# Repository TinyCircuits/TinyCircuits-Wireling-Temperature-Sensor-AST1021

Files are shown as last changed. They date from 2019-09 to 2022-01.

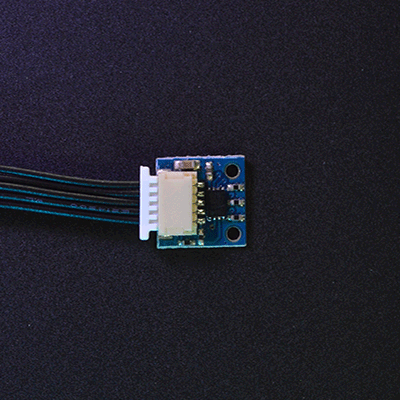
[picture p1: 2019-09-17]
images/AST1021-Tutorial-Animation-01.gif

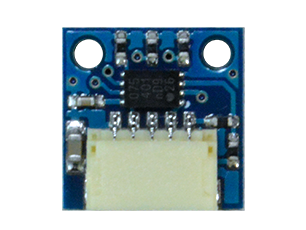
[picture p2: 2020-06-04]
images/AST1021-Learn-Photo-01.png

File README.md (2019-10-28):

# TinyCircuits Wireling Temperature Sensor
# AST1021 Rev2

The design files are located under design_files/ for the TinyCircuits AST1021 Rev 2 PCB. This is a Wireling board which features the PCT2075 Temperature Senor with 11-bit output. You've probably already guessed correctly that this sensor helps you measure the temperature in a given environment.

Format is in Cadsoft Eagle format - Eagle version 6.2 was used for the original design.

For more infomation on this, check out the product page at TinyCircuits.com

# License:

Design by TinyCircuits.
All design files are released under the Creative Commons Attribution Share-Alike 3.0 License, see the following link for details: http://creativecommons.org/licenses/by-sa/3.0

All text above must be included in any redistribution or derived design

This project uses designs and concepts developed as part of the Arduino project and the LilyPad project.  The TinyCircuits design files themselves (schematics, PCB and libraries) are not directly derived from these works' design files and have been created new, however the concepts and basic architecture behind the TinyDuino and TinyLily products are derived and we thank the hard work of the organizations below for their contributions to open-source hardware:
  
Original Arduino Uno Design by Team Arduino

LilyPad Arduino Design by Leah Buechley and Sparkfun Electronics

Please support the open-source hardware community

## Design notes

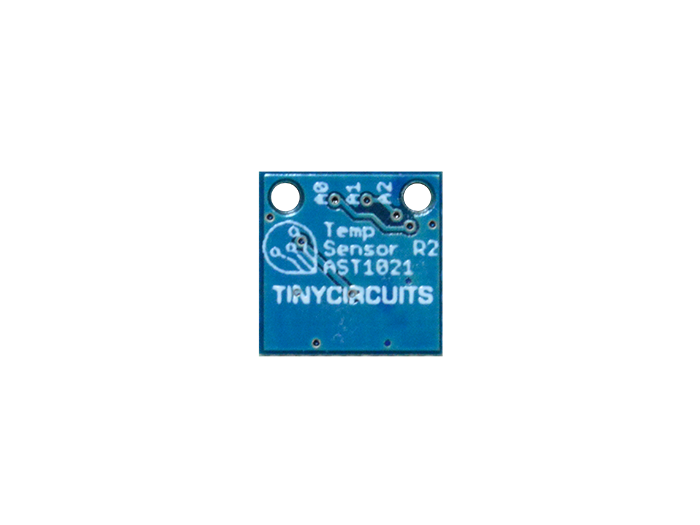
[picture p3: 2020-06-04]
images/AST1021-Product-Photo-02.png

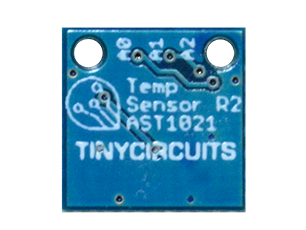
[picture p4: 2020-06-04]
images/AST1021-Learn-Photo-02.png

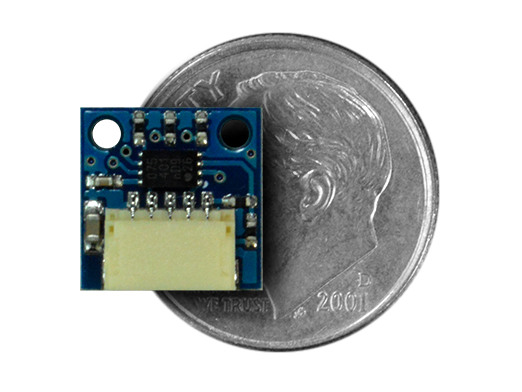
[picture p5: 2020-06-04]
images/AST1021-Product-Photo-03.png

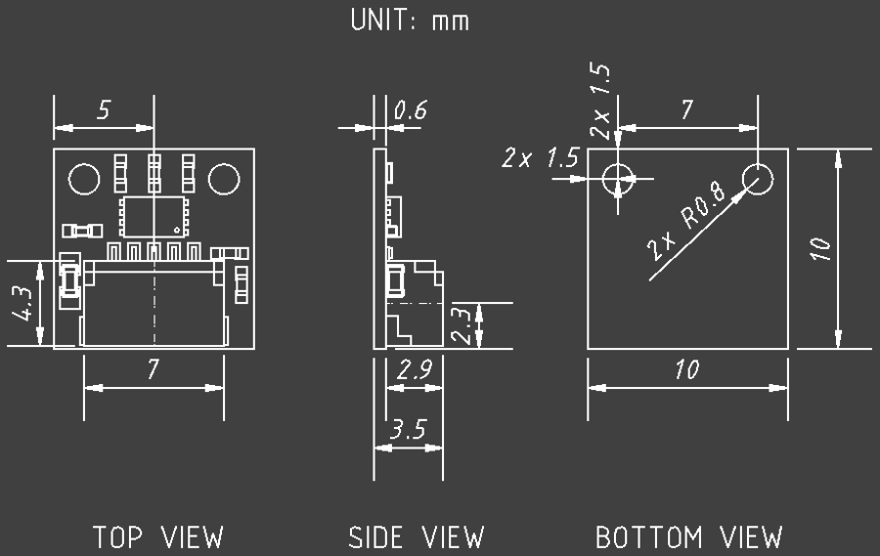
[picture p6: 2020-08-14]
cad/Wireling_TEMP_AST1021_REV2-DETAILED_DRAWING_COMPACT-PNG.png

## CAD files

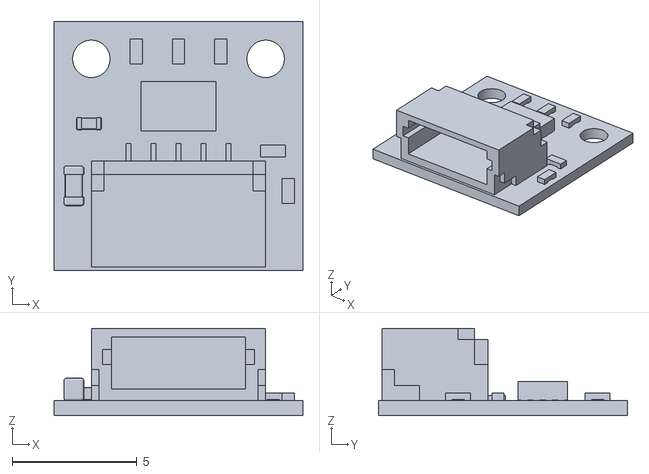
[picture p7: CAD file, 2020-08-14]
cad/Wireling_TEMP_AST1021_REV2-STL.stl
10.0 x 10.0 x 3.49

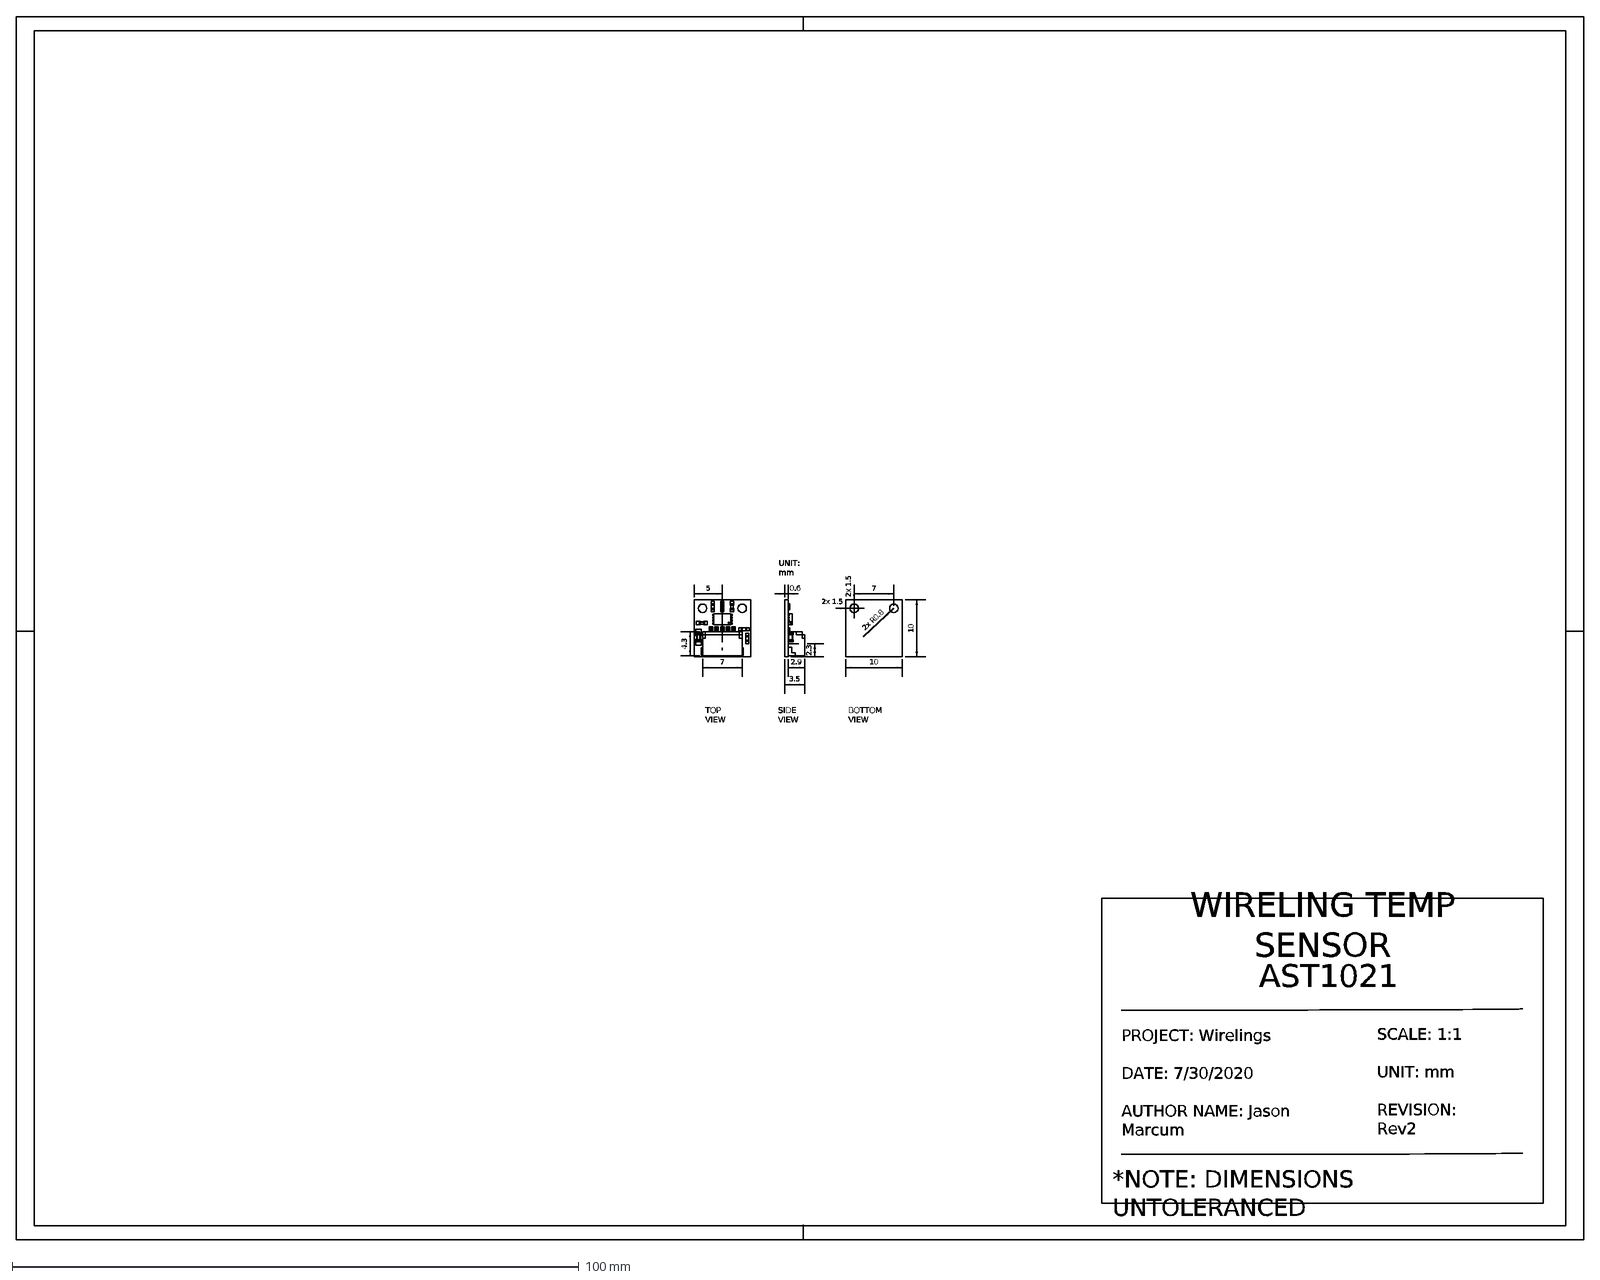
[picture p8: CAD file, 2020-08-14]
cad/Wireling_TEMP_AST1021_REV2-DETAILED_DRAWING-DXF.dxf
*NOTE: DIMENSIONS UNTOLERANCED
TOP VIEW
BOTTOM VIEW
SIDE VIEW
UNIT: mm
7
4.3
5
2.9
3.5
2.3
0.6
2x 1.5
2x R0.8
10
WIRELING TEMP SENSOR
AST1021
SCALE: 1:1 UNIT: mm REVISION: Rev2
PROJECT: Wirelings DATE: 7/30/2020 AUTHOR NAME: Jason Marcum

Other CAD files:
cad/Wireling_TEMP_AST1021_REV2-IGES.iges
cad/Wireling_TEMP_AST1021_REV2-STEP.step

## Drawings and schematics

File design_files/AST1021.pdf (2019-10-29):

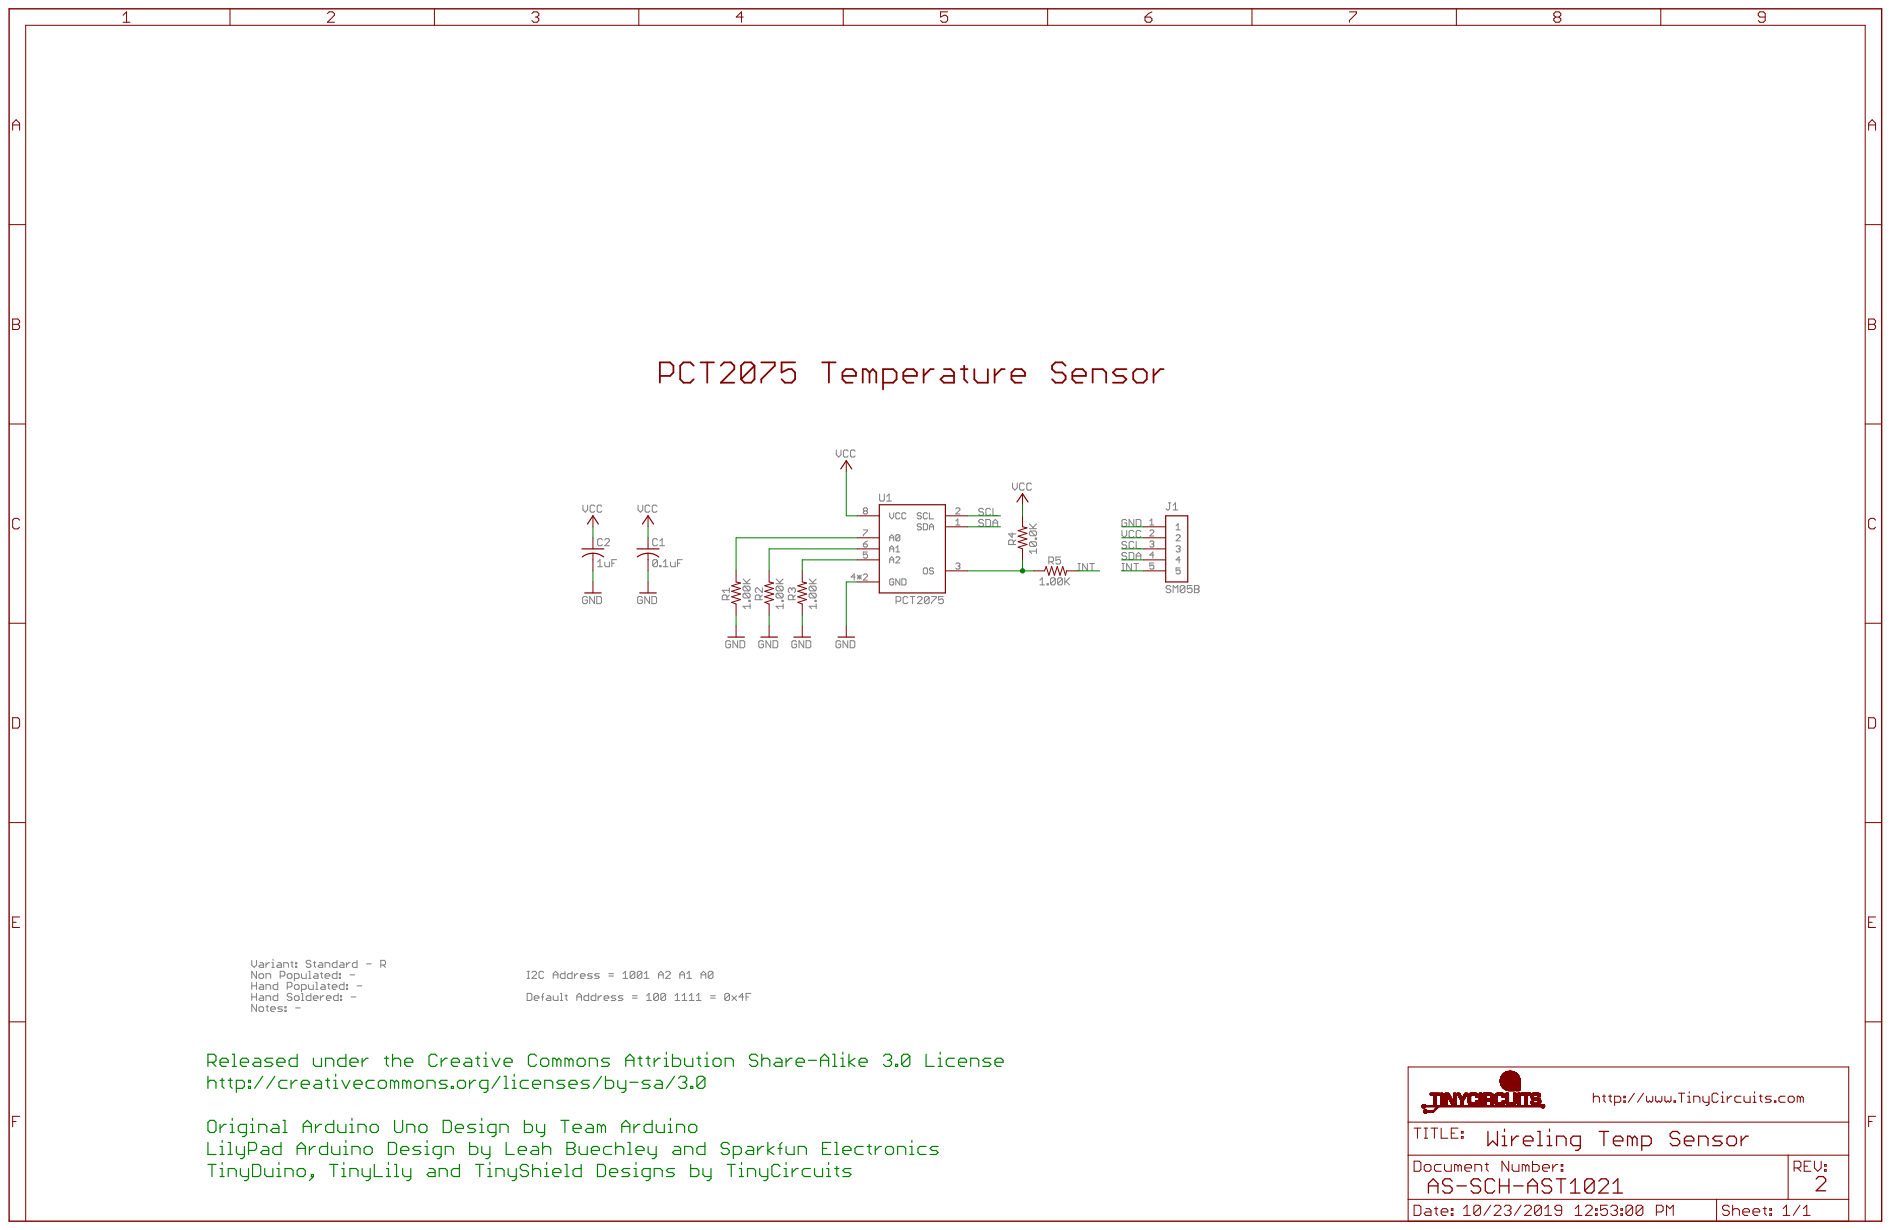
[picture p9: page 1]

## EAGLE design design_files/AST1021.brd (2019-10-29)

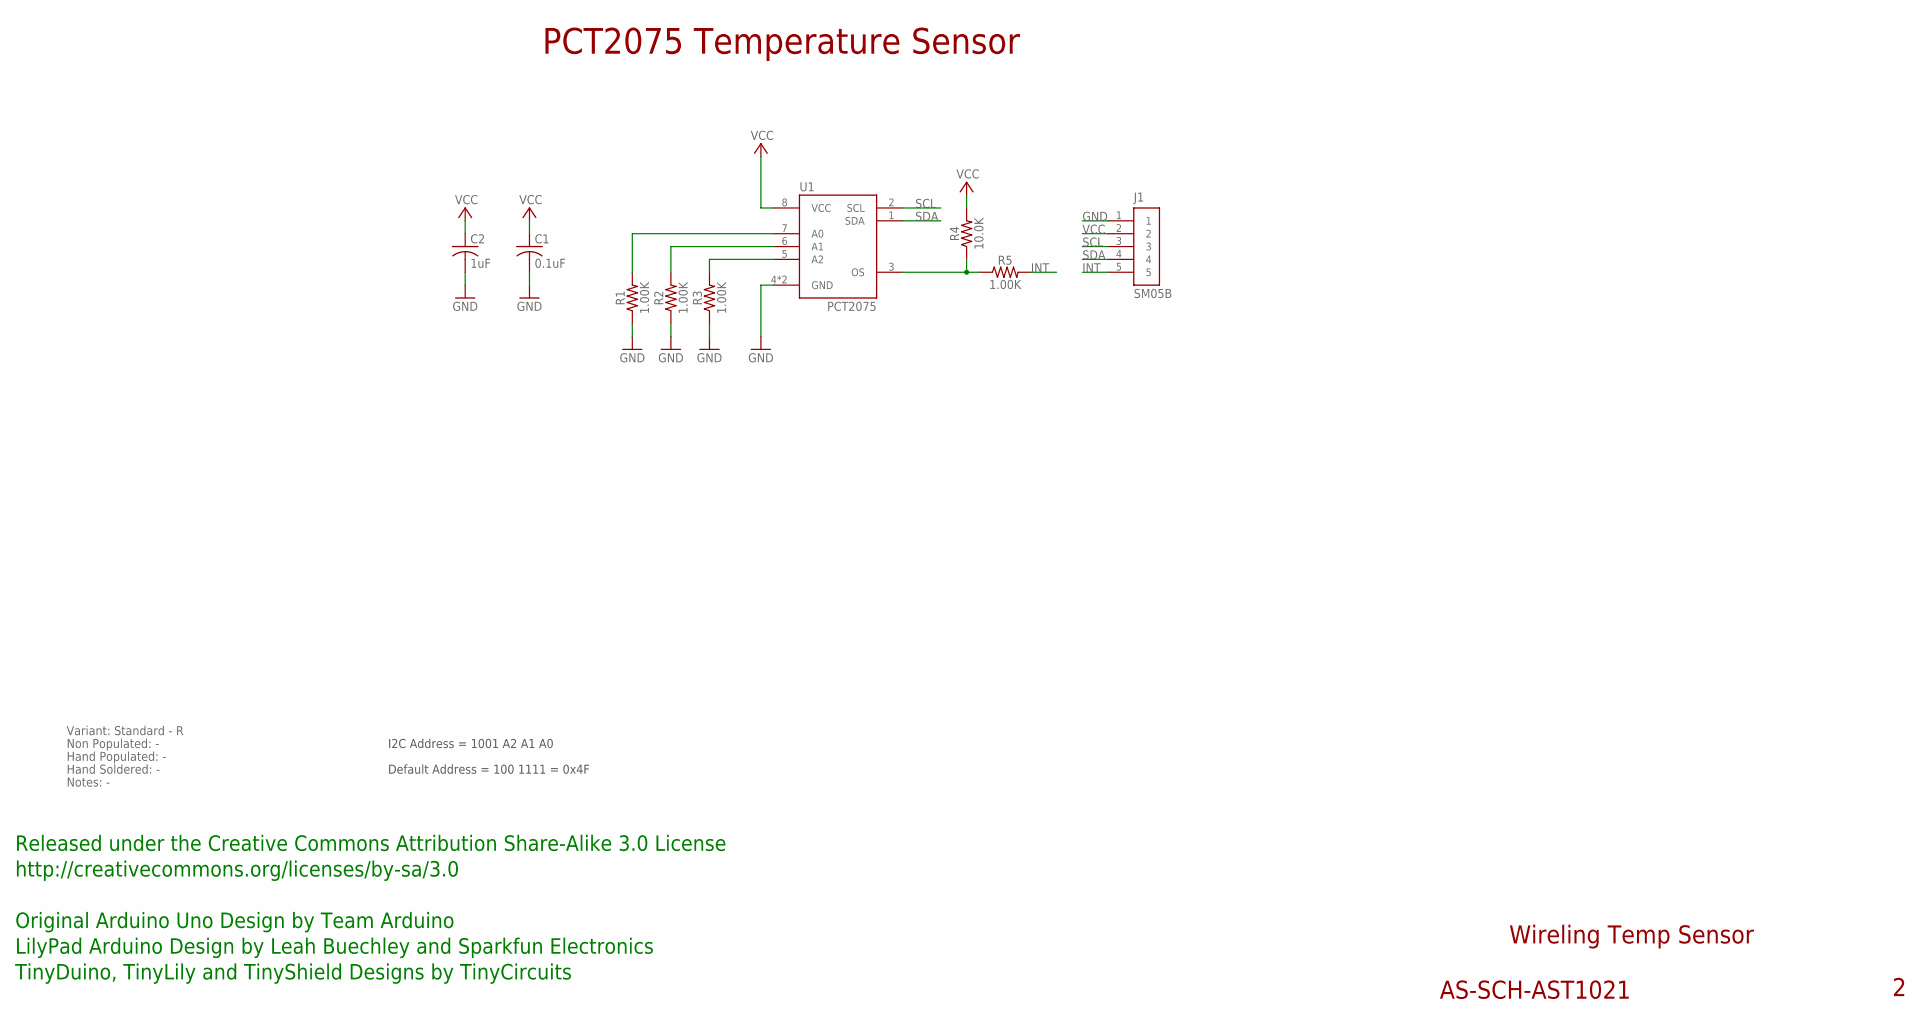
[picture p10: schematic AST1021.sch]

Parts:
C1: 0.1uF; C0402
C2: 1uF; C0603; PARTNO AS-ITM-00410
J1: SM05B; JST_SH_5X1_EDGE
R1, R2, R3, R5: 1.00K; 0402; PARTNO AS-ITM-00003
R4: 10.0K; 0402
U1: PCT2075; HWSON-8

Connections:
GND: C1.2, C2.2, J1.1, R1.1, R2.1, R3.1, U1.4 (GND), U1.GND
GPIO1: R4.1, R5.1, U1.3 (OS)
INT: J1.5, R5.2
unnamed: R1.2, U1.7 (A0)
unnamed: R2.2, U1.6 (A1)
unnamed: R3.2, U1.5 (A2)
SCL: J1.3, U1.2 (SCL)
SDA: J1.4, U1.1 (SDA)
VCC: C1.1, C2.1, J1.2, R4.2, U1.8 (VCC)

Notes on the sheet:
Wireling Temp Sensor
AS-SCH-AST1021
PCT2075 Temperature Sensor
Released under the Creative Commons Attribution Share-Alike 3.0 License
http://creativecommons.org/licenses/by-sa/3.0
Original Arduino Uno Design by Team Arduino
TinyDuino, TinyLily and TinyShield Designs by TinyCircuits
LilyPad Arduino Design by Leah Buechley and Sparkfun Electronics
I2C Address = 1001 A2 A1 A0
Default Address = 100 1111 = 0x4F
Variant: Standard - R
Non Populated: -
Hand Populated: -
Hand Soldered: -
Notes: -

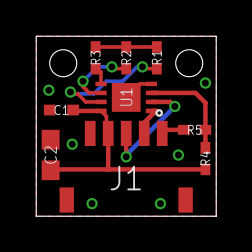
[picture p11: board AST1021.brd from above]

Board: 2 copper layers, 10.0 x 10.0 mm, 10 parts (0 on the bottom side), 9 nets.

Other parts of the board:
U$1: DOCFIELD-TINYCIRCUITS-PCB

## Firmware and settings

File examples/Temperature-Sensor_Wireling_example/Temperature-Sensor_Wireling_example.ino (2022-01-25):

/*************************************************************************
 * PCT2075 Temperature Sensor Wireling Example 
 * Reads and outputs PCT2075 values to the Serial Monitor when uploaded, 
 * including Temperature in degrees Celsius/Fahrenheit, Thyst - hysteresis, 
 * Tos - threshold, and the configuration register.
 * 
 * Initiated: 8-10-2017 by Brandon Farmer for TinyCircuits
 * Updated: 8-8-2019 by Laveréna Wienclaw for TinyCircuits
 *************************************************************************/

#include <Wire.h>
#include <TinyCircuits_PCT2075.h>
#include <Wireling.h>

TinyCircuits_PCT2075 tempSensor = TinyCircuits_PCT2075();

#if defined (ARDUINO_ARCH_AVR)
#define SerialMonitorInterface Serial
#elif defined(ARDUINO_ARCH_SAMD)
#define SerialMonitorInterface SerialUSB
#endif

void setup() {
  SerialMonitorInterface.begin(9600);
//  while(!SerialMonitorInterface);  // Blocks sensor printing data until Serial Monitor is opened

  // Enable and Power wirelings
  Wireling.begin();
  
  Wire.begin(); // begin I2C communication
  Wireling.selectPort(0);
//  const int tempPin = 0;       //IO Pin D2 = Interrupt Pin 0 

  //Initialize the sensor with config settings
  tempSensor.begin(PCT2075_ACTIVE_LOW, PCT2075_COMPARATOR, PCT2075_NORMAL, PCT2075_FAULT_6X);

//  pinMode(tempPin, INPUT_PULLUP);
//  attachInterrupt(digitalPinToInterrupt(tempPin), interruptServiceRoutine, FALLING);

  tempSensor.wake(); // Wake up the module
}

void loop() {
  float rawTemp = tempSensor.readTemp() / 32.0; // Divide by 32 to get rid of empty 5 LSB
  float tempC = (rawTemp * 0.125); // Conversion to degreesC noted on page 11 of datasheet
  float tempF = (tempC * 1.8 + 32); // Conversion from degreeC to degreeF

  if (tempSensor.checkMode() == 0) {
    tempSensor.writeOvertemp(30);
    tempSensor.writeHyst(29);
    
    SerialMonitorInterface.print("Temp.C = ");
    SerialMonitorInterface.print(tempC);
    SerialMonitorInterface.print(" C");
    SerialMonitorInterface.print("\t");
    SerialMonitorInterface.print("Temp.F = ");
    SerialMonitorInterface.print(tempF);
    SerialMonitorInterface.print(" F");
    SerialMonitorInterface.print("\t");
    SerialMonitorInterface.print("Thyst = "); // Hysteresis 
    SerialMonitorInterface.print(tempSensor.readHyst()); 
    SerialMonitorInterface.print("C");
    SerialMonitorInterface.print("\t");
    SerialMonitorInterface.print("Tos = "); // Threshold
    SerialMonitorInterface.print(tempSensor.readTos()); 
    SerialMonitorInterface.print("C");
    SerialMonitorInterface.print("\t");
    SerialMonitorInterface.print("Config: ");
    SerialMonitorInterface.print("0b");
    SerialMonitorInterface.print(tempSensor.readConfig(), BIN);
    SerialMonitorInterface.print("\t");
    SerialMonitorInterface.print("Mode = ");
    SerialMonitorInterface.println(tempSensor.checkMode()); 
    SerialMonitorInterface.println("---------------------------------------------------------------------------------------------------------------------------");

    delay(250);
//    tempSensor.sleep();
  }
  else {
    SerialMonitorInterface.println("SENSOR IN SLEEP MODE!"); 
    SerialMonitorInterface.println(tempSensor.readConfig(), BIN);
    tempSensor.wake(); 
    delay(250);  
  }
}

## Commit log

2019-08-08 added necessary folders
    [AST1021.brd, AST1021.sch]
2019-10-29 name change
    [AST1021.brd, AST1021.sch]
2020-08-14 Add CAD data
    [Wireling_TEMP_AST1021_REV2-DETAILED_DRAWING-DXF.dxf, Wireling_TEMP_AST1021_REV2-IGES.iges, Wireling_TEMP_AST1021_REV2-STEP.step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]
